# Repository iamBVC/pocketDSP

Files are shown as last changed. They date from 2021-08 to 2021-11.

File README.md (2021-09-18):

# pocketDSP
A pocket-sized DSP for audio applications.

This device consists in a STM32H732 MCU, 24bit 192kHz ADC/DAC with high SiNAD, low noise opamp buffers, 3.5mm stereo jack input/output, 480x320 touchscreen display, li-ion battery and USB for battery recharging and Virtual COM Port.

Functions:

DSP: Create your own FX preset by selecting various standalone effects such as reverb, delay, phaser, IIR/FIR filters via the touchscreen display. Save/Load in the SD Card.

Spectrum Analyzer: Applies the FFT algorithm to the input signal, makes measurements on the amplitude of the harmonics and saves the data on the SD card.

Sound card: Connect the device to your pc to use it as a HiFi USB Sound Card.

Synthesizer: send midi commands through the USB interface and create sounds using the display to change the oscillators and effects parameters.

-- software still under development --

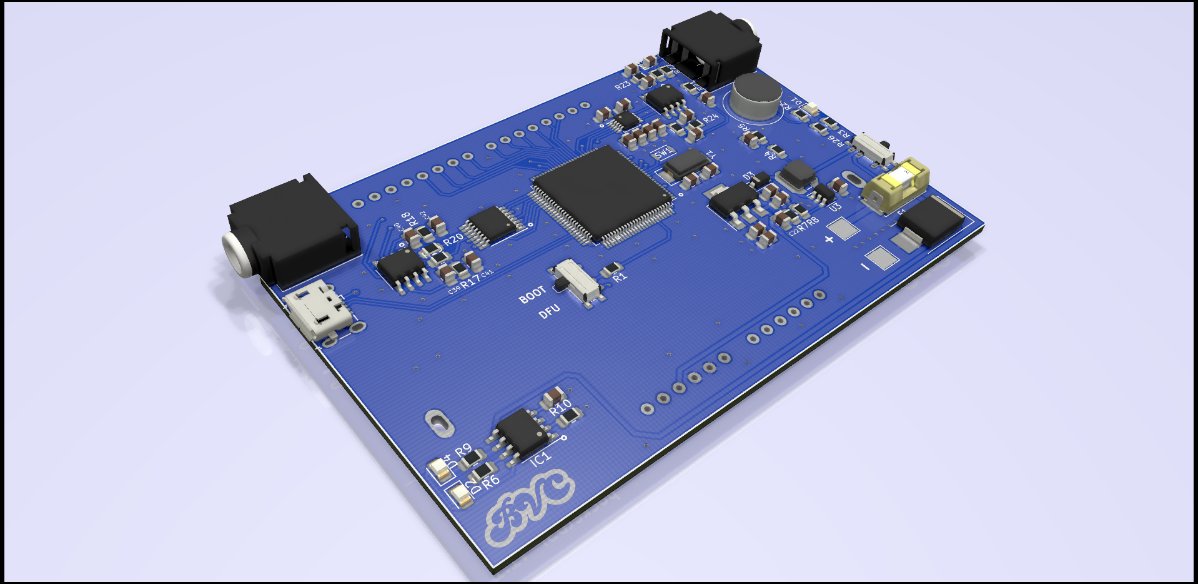
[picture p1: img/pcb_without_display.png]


GUI Screens:

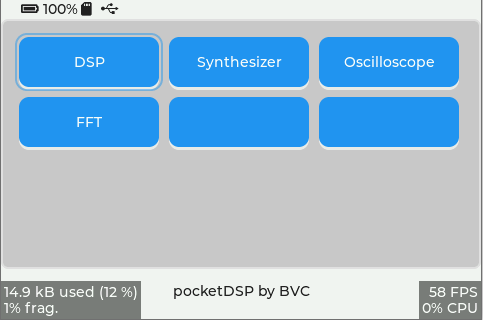
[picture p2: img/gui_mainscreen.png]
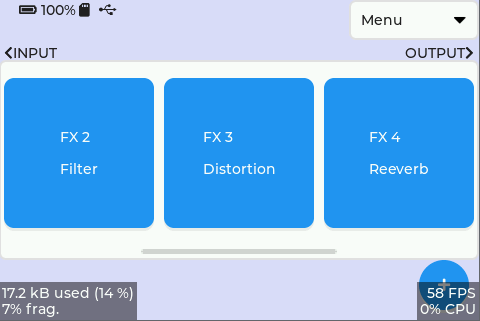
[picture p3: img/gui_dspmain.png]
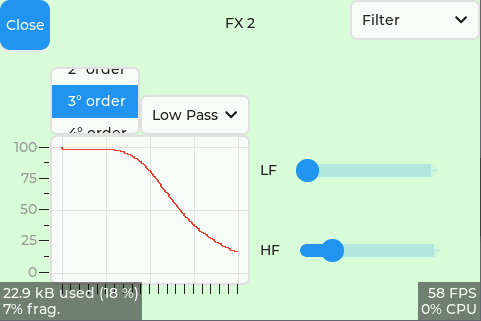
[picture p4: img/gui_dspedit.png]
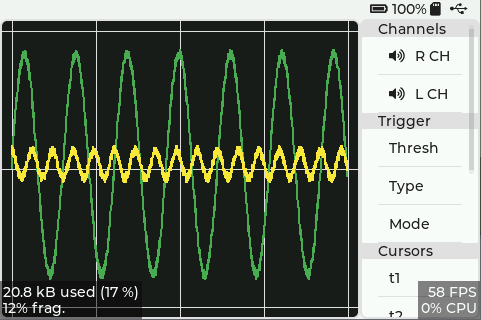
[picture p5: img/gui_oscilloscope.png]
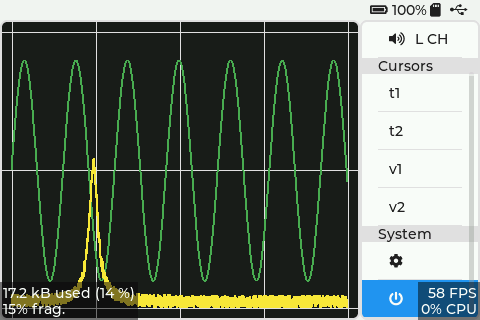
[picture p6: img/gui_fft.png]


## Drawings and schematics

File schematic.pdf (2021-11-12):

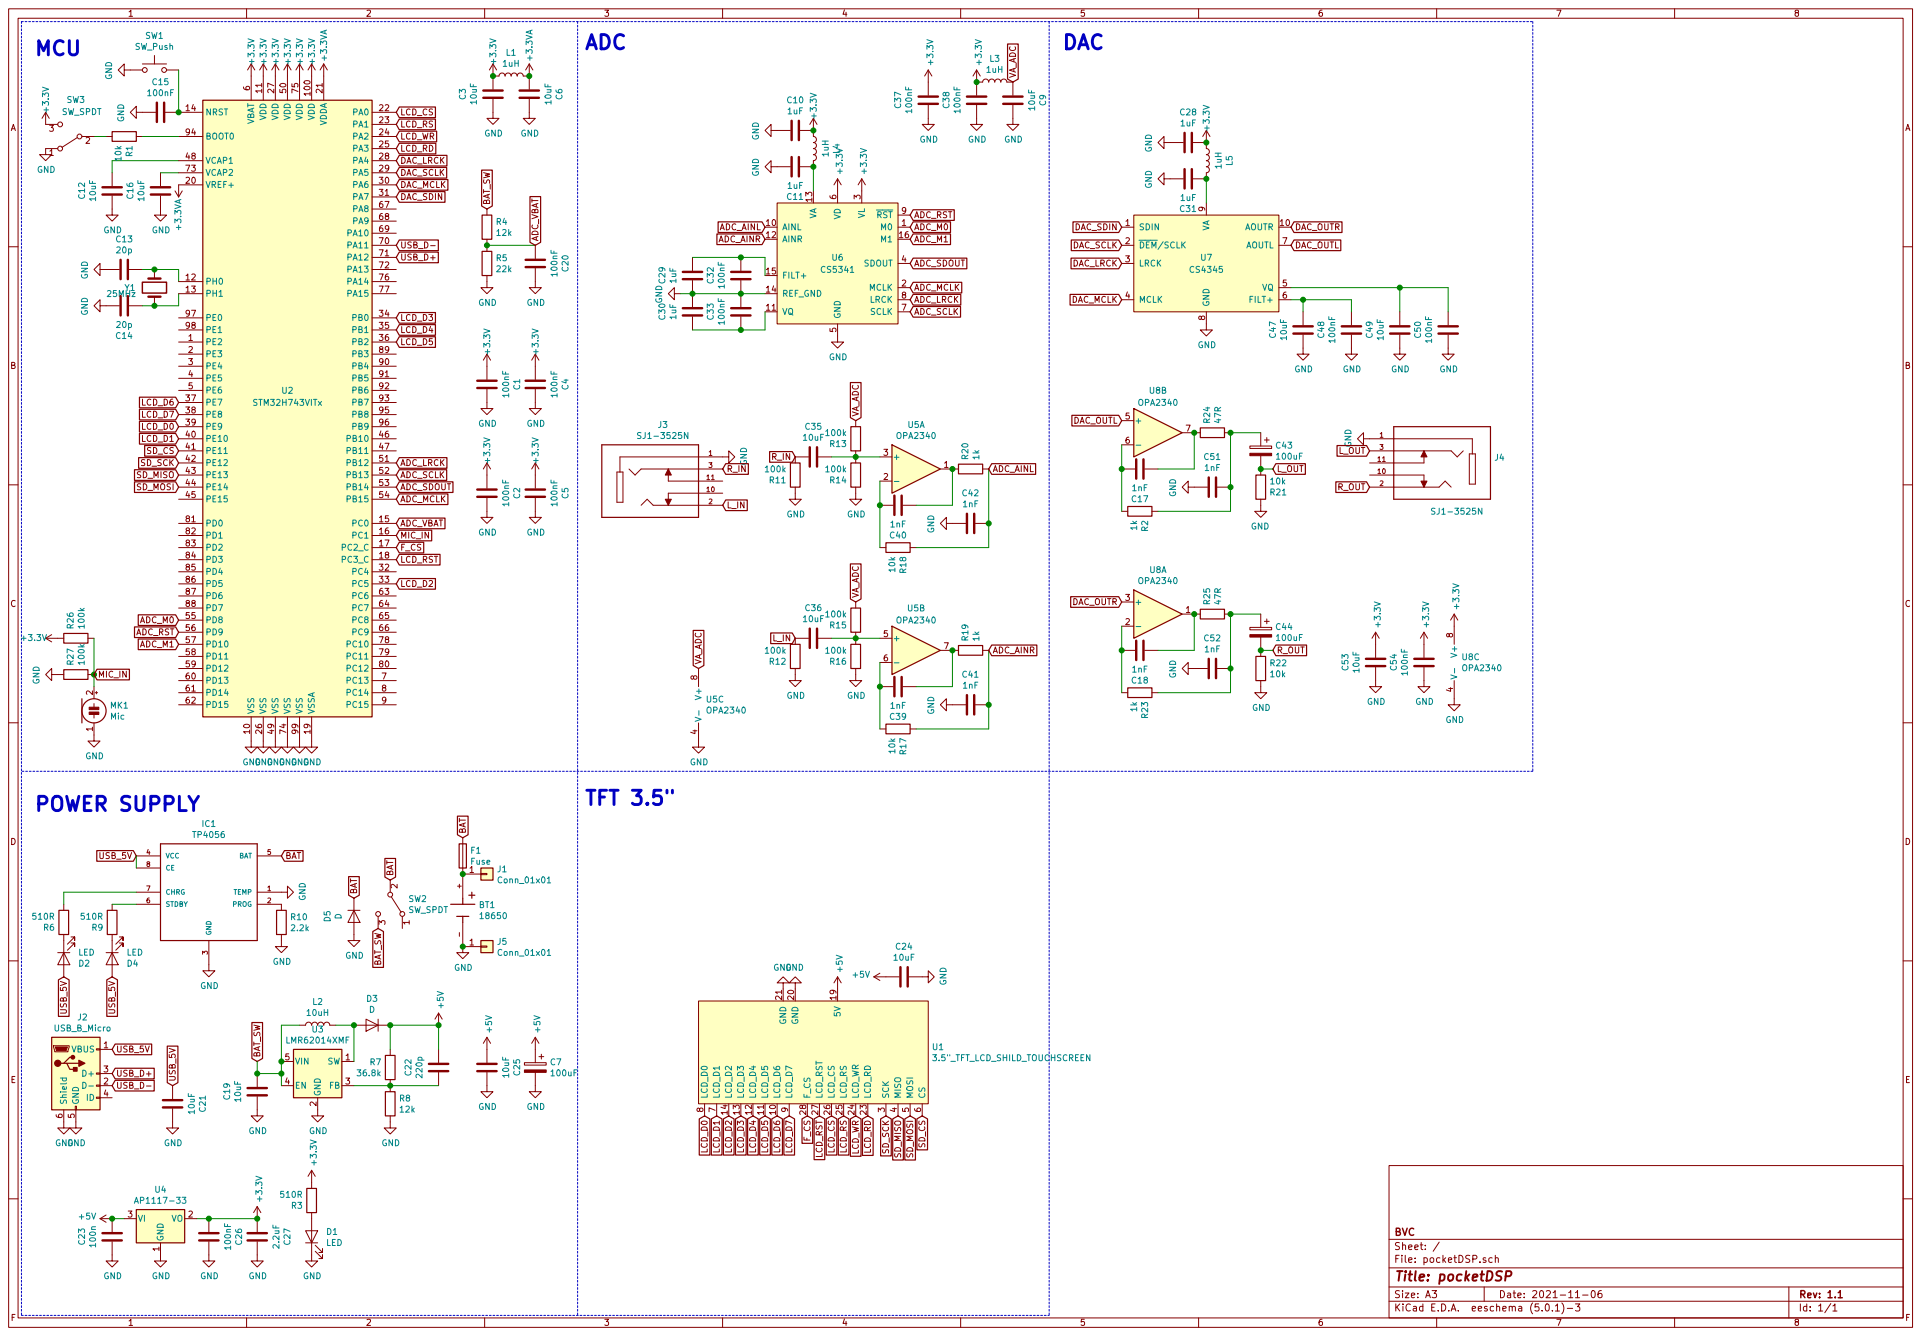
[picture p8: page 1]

1 VO 2 VI 3 U4 AP1117-33 +3.3V 10uF C21 GND +3.3V +3.3V +3.3V +3.3V +3.3V +3.3V C12 10uF C16 10uF GND GND GNDGNDGNDGNDGNDGND

6 VCAP1 48 VCAP2 73 VDD 100 VDD 11 VDD 27 VDD 50 VDD 75 VDDA 21 VREF+ 20 VSS 10 VSS 26 VSS 49 VSS 74 VSS 99 VSSA 19 U2 STM32H743VITx ADC_VBAT R24 47R

9 U7 CS4345 M0 1 AINL 10 VQ 11 AINR 12 VA 13 REF_GND 14 FILT+ 15 M1 16 MCLK 2 VL

3 VCC 4 BAT 5 STDBY 6 CHRG 7 CE 8

File: pocketDSP.sch Sheet: / BVC

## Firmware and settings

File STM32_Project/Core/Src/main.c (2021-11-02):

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
/* Includes ------------------------------------------------------------------*/
#include "main.h"
#include "usb_device.h"

/* USER CODE BEGIN Includes */
#include "tft.h"
#include "system.h"
/* USER CODE END Includes */

ADC_HandleTypeDef hadc1;

I2S_HandleTypeDef hi2s1;
I2S_HandleTypeDef hi2s2;

SPI_HandleTypeDef hspi4;

TIM_HandleTypeDef htim12;
TIM_HandleTypeDef htim13;
TIM_HandleTypeDef htim14;
TIM_HandleTypeDef htim16;
TIM_HandleTypeDef htim17;

/* USER CODE BEGIN PV */

lv_disp_draw_buf_t draw_buf;
__attribute__ ((section(".RAMD3"),used)) lv_color_t buf1[480 * 32];
__attribute__ ((section(".RAMD3"),used)) lv_color_t buf2[480 * 32];
lv_disp_drv_t disp_drv;
lv_indev_drv_t indev_drv;
uint16_t ts_x, ts_y, ts_z;

/* USER CODE END PV */

void SystemClock_Config(void);
void PeriphCommonClock_Config(void);
static void MX_GPIO_Init(void);
static void MX_TIM16_Init(void);
static void MX_TIM17_Init(void);
static void MX_I2S2_Init(void);
static void MX_I2S1_Init(void);
static void MX_ADC1_Init(void);
static void MX_SPI4_Init(void);
static void MX_TIM13_Init(void);
static void MX_TIM14_Init(void);
static void MX_TIM12_Init(void);
/* USER CODE BEGIN 0 */

void my_disp_flush(lv_disp_drv_t *disp, lv_area_t *area, lv_color_t *color_p) {

	drawScreen((uint16_t*) color_p, area);
	lv_disp_flush_ready(disp); /* Indicate you are ready with the flushing*/
}

void my_touchpad_read(lv_indev_t *indev, lv_indev_data_t *data) {

	readTouch(&ts_x, &ts_y, &ts_z);
	if (ts_z >= 300)
		data->state = LV_INDEV_STATE_PR;
	else
		data->state = LV_INDEV_STATE_REL;

	if (data->state == LV_INDEV_STATE_PR) {
		data->point.x = ts_x;
		data->point.y = ts_y;
	}

}

/* USER CODE END 0 */

/**
  * @brief  The application entry point.
  * @retval int
  */
int main(void)
{
  /* Enable I-Cache---------------------------------------------------------*/
  SCB_EnableICache();

  /* Enable D-Cache---------------------------------------------------------*/
  SCB_EnableDCache();

  /* MCU Configuration--------------------------------------------------------*/

  /* Reset of all peripherals, Initializes the Flash interface and the Systick. */
  HAL_Init();

  /* Configure the system clock */
  SystemClock_Config();

/* Configure the peripherals common clocks */
  PeriphCommonClock_Config();

  /* USER CODE BEGIN SysInit */

  //wait for the DAC/ADC capacitors charge to 1.67V
  GPIO_InitTypeDef GPIO_InitStruct;
  __HAL_RCC_GPIOA_CLK_ENABLE();
  HAL_GPIO_WritePin(GPIOA, GPIO_PIN_4, GPIO_PIN_RESET);
  HAL_GPIO_WritePin(GPIOA, GPIO_PIN_5, GPIO_PIN_RESET);
  HAL_GPIO_WritePin(GPIOA, GPIO_PIN_6, GPIO_PIN_RESET);
  HAL_GPIO_WritePin(GPIOA, GPIO_PIN_7, GPIO_PIN_RESET);
  GPIO_InitStruct.Pin = GPIO_PIN_4|GPIO_PIN_5|GPIO_PIN_6|GPIO_PIN_7;
  GPIO_InitStruct.Mode = GPIO_MODE_OUTPUT_PP;
  GPIO_InitStruct.Speed = GPIO_SPEED_FREQ_VERY_HIGH;
  HAL_GPIO_Init(GPIOA, &GPIO_InitStruct);
  HAL_Delay(500);

  /* USER CODE END SysInit */

  /* Initialize all configured peripherals */
  MX_GPIO_Init();
  MX_TIM16_Init();
  MX_USB_DEVICE_Init();
  MX_TIM17_Init();
  MX_I2S2_Init();
  MX_I2S1_Init();
  MX_ADC1_Init();
  MX_SPI4_Init();
  MX_TIM13_Init();
  MX_TIM14_Init();
  MX_TIM12_Init();
  /* USER CODE BEGIN 2 */


	HAL_ADC_Start(&hadc1); //internal DAC start
	HAL_TIM_Base_Start(&htim16); //delay us timer

	//TFT init
	uint16_t ID = readID();
	HAL_Delay(100);
	tft_init(ID);
	setRotation(1);
	fillScreen(BLACK);

	//gui init
	lv_init();
	lv_disp_draw_buf_init(&draw_buf, buf1, buf2, 480 * 32);
	lv_disp_drv_init(&disp_drv);
	disp_drv.flush_cb = my_disp_flush;
	disp_drv.draw_buf = &draw_buf;
	disp_drv.hor_res = 480;
	disp_drv.ver_res = 320;
	lv_disp_drv_register(&disp_drv);
	lv_indev_drv_init(&indev_drv);
	indev_drv.type = LV_INDEV_TYPE_POINTER;
	indev_drv.read_cb = my_touchpad_read;
	lv_indev_drv_register(&indev_drv);
	HAL_TIM_Base_Start_IT(&htim17); //lvgl tick timer

	DAC_Init();
	ADC_Init();
	dsp_fx_init();
	sample_callback = &play_startup_sound;
	HAL_TIM_Base_Start_IT(&htim14); //sampling timer
	logo_screen();
	reset_app(); //start gui


  /* USER CODE END 2 */

  /* Infinite loop */
  /* USER CODE BEGIN WHILE */
	while (1) {
    /* USER CODE END WHILE */

    /* USER CODE BEGIN 3 */
		sys_status_refresh();
		lv_task_handler();
		lv_timer_handler();
		HAL_Delay(5);

	}
  /* USER CODE END 3 */
}

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
/* USER CODE BEGIN 4 */
void HAL_TIM_PeriodElapsedCallback(TIM_HandleTypeDef *htim) {

	if (htim == &htim17) {
		lv_tick_inc(1);
	}

	if (htim == &htim14) {
		sample_callback();
	}

}
/* USER CODE END 4 */
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


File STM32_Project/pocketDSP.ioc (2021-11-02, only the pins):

Mcu.UserName=STM32H743VITx
PA0.GPIO_Label=LCD_CS
PA0.Signal=GPIO_Output
PA1.GPIO_Label=LCD_CD
PA1.Signal=GPIO_Output
PA11.Signal=USB_OTG_FS_DM
PA12.Signal=USB_OTG_FS_DP
PA2.GPIO_Label=LCD_WR
PA2.Signal=GPIO_Output
PA3.GPIO_Label=LCD_RD
PA3.Signal=GPIO_Output
PA4.GPIO_Label=DAC_LRCK
PA4.Signal=I2S1_WS
PA5.GPIO_Label=DAC_SCLK
PA5.Signal=I2S1_CK
PA6.GPIO_Label=DAC_MCLK
PA6.Signal=S_TIM13_CH1
PA7.GPIO_Label=DAC_SDIN
PA7.Signal=I2S1_SDO
PB0.GPIO_Label=LCD_D3
PB0.Signal=GPIO_Output
PB1.GPIO_Label=LCD_D4
PB1.Signal=GPIO_Output
PB12.GPIO_Label=ADC_LRCK
PB12.Signal=I2S2_WS
PB13.GPIO_Label=ADC_SCLK
PB13.Signal=I2S2_CK
PB14.GPIO_Label=ADC_SDOUT
PB14.Signal=I2S2_SDI
PB15.GPIO_Label=ADC_MCLK
PB15.Signal=S_TIM12_CH2
PB2.GPIO_Label=LCD_D5
PB2.Signal=GPIO_Output
PC0.GPIO_Label=VBAT
PC0.Signal=ADCx_INP10
PC2_C.GPIO_Label=F_CS
PC2_C.Signal=GPIO_Output
PC3_C.GPIO_Label=LCD_RST
PC3_C.Signal=GPIO_Output
PC5.GPIO_Label=LCD_D2
PC5.Signal=GPIO_Output
PD10.GPIO_Label=ADC_RST
PD10.Signal=GPIO_Output
PD8.GPIO_Label=ADC_M0
PD8.Signal=GPIO_Output
PD9.GPIO_Label=ADC_M1
PD9.Signal=GPIO_Output
PE10.GPIO_Label=LCD_D1
PE10.Signal=GPIO_Output
PE11.GPIO_Label=SD_CS
PE11.Signal=GPIO_Output
PE12.GPIO_Label=SD_SCK
PE12.Signal=SPI4_SCK
PE13.GPIO_Label=SD_MISO
PE13.Signal=SPI4_MISO
PE14.GPIO_Label=SD_MOSI
PE14.Signal=SPI4_MOSI
PE7.GPIO_Label=LCD_D6
PE7.Signal=GPIO_Output
PE8.GPIO_Label=LCD_D7
PE8.Signal=GPIO_Output
PE9.GPIO_Label=LCD_D0
PE9.Signal=GPIO_Output

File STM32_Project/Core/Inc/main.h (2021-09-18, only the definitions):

#define VBAT_Pin GPIO_PIN_0
#define VBAT_GPIO_Port GPIOC
#define F_CS_Pin GPIO_PIN_2
#define F_CS_GPIO_Port GPIOC
#define LCD_RST_Pin GPIO_PIN_3
#define LCD_RST_GPIO_Port GPIOC
#define LCD_CS_Pin GPIO_PIN_0
#define LCD_CS_GPIO_Port GPIOA
#define LCD_CD_Pin GPIO_PIN_1
#define LCD_CD_GPIO_Port GPIOA
#define LCD_WR_Pin GPIO_PIN_2
#define LCD_WR_GPIO_Port GPIOA
#define LCD_RD_Pin GPIO_PIN_3
#define LCD_RD_GPIO_Port GPIOA
#define DAC_LRCK_Pin GPIO_PIN_4
#define DAC_LRCK_GPIO_Port GPIOA
#define DAC_SCLK_Pin GPIO_PIN_5
#define DAC_SCLK_GPIO_Port GPIOA
#define DAC_MCLK_Pin GPIO_PIN_6
#define DAC_MCLK_GPIO_Port GPIOA
#define DAC_SDIN_Pin GPIO_PIN_7
#define DAC_SDIN_GPIO_Port GPIOA
#define LCD_D2_Pin GPIO_PIN_5
#define LCD_D2_GPIO_Port GPIOC
#define LCD_D3_Pin GPIO_PIN_0
#define LCD_D3_GPIO_Port GPIOB
#define LCD_D4_Pin GPIO_PIN_1
#define LCD_D4_GPIO_Port GPIOB
#define LCD_D5_Pin GPIO_PIN_2
#define LCD_D5_GPIO_Port GPIOB
#define LCD_D6_Pin GPIO_PIN_7
#define LCD_D6_GPIO_Port GPIOE
#define LCD_D7_Pin GPIO_PIN_8
#define LCD_D7_GPIO_Port GPIOE
#define LCD_D0_Pin GPIO_PIN_9
#define LCD_D0_GPIO_Port GPIOE
#define LCD_D1_Pin GPIO_PIN_10
#define LCD_D1_GPIO_Port GPIOE
#define SD_CS_Pin GPIO_PIN_11
#define SD_CS_GPIO_Port GPIOE
#define SD_SCK_Pin GPIO_PIN_12
#define SD_SCK_GPIO_Port GPIOE
#define SD_MISO_Pin GPIO_PIN_13
#define SD_MISO_GPIO_Port GPIOE
#define SD_MOSI_Pin GPIO_PIN_14
#define SD_MOSI_GPIO_Port GPIOE
#define ADC_LRCK_Pin GPIO_PIN_12
#define ADC_LRCK_GPIO_Port GPIOB
#define ADC_SCLK_Pin GPIO_PIN_13
#define ADC_SCLK_GPIO_Port GPIOB
#define ADC_SDOUT_Pin GPIO_PIN_14
#define ADC_SDOUT_GPIO_Port GPIOB
#define ADC_MCLK_Pin GPIO_PIN_15
#define ADC_MCLK_GPIO_Port GPIOB
#define ADC_M0_Pin GPIO_PIN_8
#define ADC_M0_GPIO_Port GPIOD
#define ADC_M1_Pin GPIO_PIN_9
#define ADC_M1_GPIO_Port GPIOD
#define ADC_RST_Pin GPIO_PIN_10
#define ADC_RST_GPIO_Port GPIOD

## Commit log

2021-08-08 gerber files for JLCPCB
    [Guitar DSP-B.Cu.gbr, Guitar DSP-B.Mask.gbr, Guitar DSP-B.Paste.gbr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]
2021-08-08 PCB 3D render with KiCad
2021-08-08 C code for STM32CubeIDE
2021-08-27 STM32CubeIDE Project Files
2021-08-29 STM32CubeIDE Project
2021-09-20 CS4345 DAC drivers fixed
    [CS4345_test.ioc, main.c, pocketDSP.ioc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]
2021-11-02 v1.00.001
    [Release info]
    DSP:
    Done: Implemented effects Distortion, FIR Filter, Delay, Reeverb.
    To do: implement other FXs, add menu to save/load presets and change ADC/DAC resolutions/sampling frequency.
    Synthesizer:
    Done: none LOL.
    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
2021-11-12 PCB v1.1
    - Reduced DC/DC Converter ripple
    - Added on PCB microphone
    - Changed SMD from 0402 to 0805
    - Improved total SNR
    - Added reset push button
    [pocketDSP-B.Cu.gbr, pocketDSP-B.Mask.gbr, pocketDSP-B.Paste.gbr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]

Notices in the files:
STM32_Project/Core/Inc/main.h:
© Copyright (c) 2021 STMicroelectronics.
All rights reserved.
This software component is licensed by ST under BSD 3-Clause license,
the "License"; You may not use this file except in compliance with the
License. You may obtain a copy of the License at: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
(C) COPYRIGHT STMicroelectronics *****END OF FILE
